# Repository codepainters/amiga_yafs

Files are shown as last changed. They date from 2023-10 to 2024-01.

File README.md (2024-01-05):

# Yet Another FDD Swapper for Amiga 500

This is my project of Amiga FDD swapper, based on `ATtiny 404` MCU. 

## What it does?

It allows for swapping internal `DF0:` drive and `DF1:` external drive (by crossing `SEL0` and `SEL1` signals from `MOS 8520 EVEN CIA`). Holding `Ctrl - Amiga - Amiga` keys for at least 2 seconds switches between normal / swapped configurations. The last used configuration is automatically restored on power up (unless configured not to do so, see below). Switching is confirmed with 1 (for normal) or 2 (for swapped) beeps.

The project consists of 2 separate PCBs:

* a bigger one that goes under the `EVEN CIA` chip - responsible for `SEL0` / `SEL1` swapping.
* a smaller one that which goes between Amiga motherboard and floppy ribbon cable. This PCB allows for internal FDD to be detected as DF1 (it's optional).

This is how the boards look like assembled in my Amiga 500 Rev 6A.

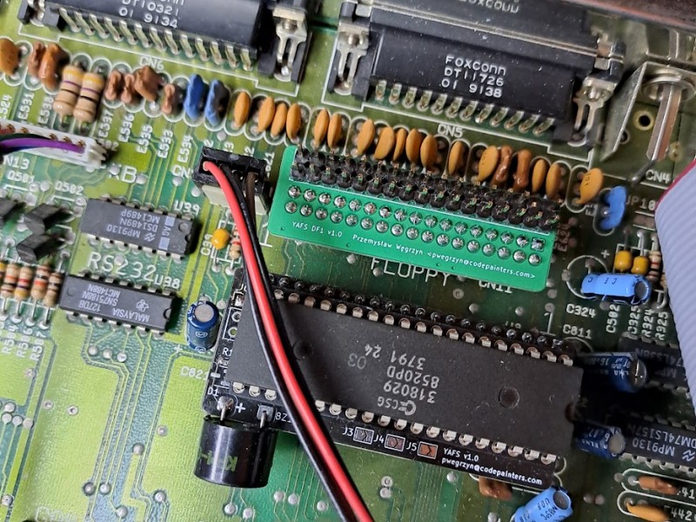
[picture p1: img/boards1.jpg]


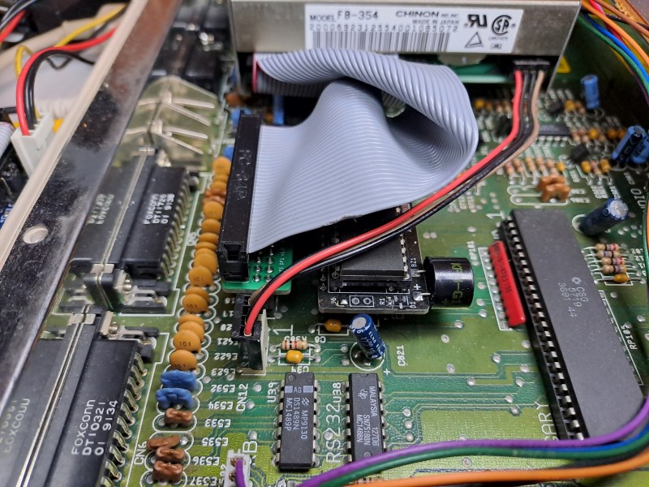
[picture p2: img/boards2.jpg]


## Why another one?

Well, there are many FDD swapper projects already, all of these mods basically swap `SEL0` and `SEL1` of the `Even CIA`, using anything from simple mechanical switch to `74LS153` multiplexer (or even `4066` CMOS analog switch) driven by `ATtiny` MCU. Please note, that swapping `SEL0/1` signals is not enough for internal drive to work as `DF1:`, additional circuitry is needed to drive `~RDY` signal during the drive enumeration at boot time.

Looking for a solution, I've found [Amiga Floppy Swap](https://github.com/retronicdesign/AmigaFloppySwap) project, which is almost exactly what I need. However, I decided to make it slightly simpler:

* my project uses only a single chip, `ATtiny 404` microcontroller, which costs below **0.50 EUR** (at least at the time of this writing),
* the smaller board (which allows for internal drive being enumerated as `DF1:`) doesn't need to be connected with the bigger board. Actually it contains only 2 MOSFETs and 2 resistors and doesn't need any extra connections, beside the floppy flat cable (not even +5V supply!). 
* it is configurable - one can chose if it beeps on every start (or only when changing the configuration) and which configuration (last used vs always swapped vs always straight) it should use upon powering up (see [pcb_cia](pcb_cia) description for details).
* the smaller board is plugged into the mainboard (as opposed to between the cable and FDD) - this way possible collision with the EMI shielding sheet metal is entirely avoided.

Also, it's fun to make something new (even if reinventing the wheel).

## Project files

This repository contains 3 main directories (look there for more details, assembly instructions, etc.):

* [pcb_cia](pcb_cia) - KiCAD project of the bigger PCB which goes under the `CIA` chip.
* [pcb_df1](pcb_df1) - KiCAD project of the smaller PCB which goes between Amiga motherboard and the FDD ribbon cable. 

* [firmware](firmware) for the `ATtiny 404` MCU on the `pcb_cia` board (including programming instructions).

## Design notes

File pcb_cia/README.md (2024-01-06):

# CIA board

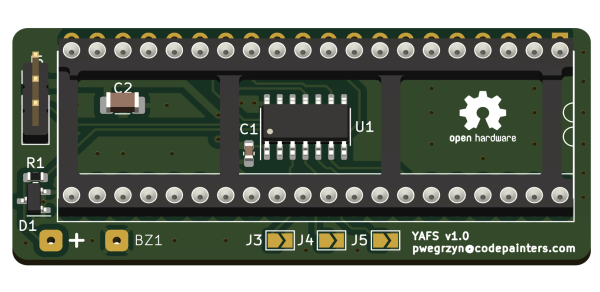
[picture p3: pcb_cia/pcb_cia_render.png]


* [schematics in PDF format](pcb_cia.pdf)
* [Gerbers and Excellon](production/pcb_cia.zip)
* [BOM](production/bom.csv)

Note:

* for `BZ1` buzzer I have used `KPM1201A` magnetic buzzer, but pretty much anything should work, as long as U1 maximum output current (20 mA) is not exceeded. You may need to adjust R1 value.
* I've added `D1` diode as a back EMF protection, but it turned out it is not really necessary with the buzzer I use. 
* for programming instructions, see [here](../firmware)

## Configuration

The J3, J4 and J5 solder bridge jumpers can be used to configure the device:

* if `J3` is open, the buzzer beeps only to confirm the mode changing, if `J3` is closed the buzzer beeps (once or twice) at each power-up, to remind what mode is currently selected.
* if `J4` is open, last used mode is restored on power-up. If it is closed, the same mode is selected at each power-up - swapped (if `J5` is open) or normal (if `J5` is closed). If `J4` is open, `J5` state is ignored.

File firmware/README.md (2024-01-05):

# Firmware

This directory contains the YAFS firmware source code.

**Note:** If you don't want to compile it yourself, you can use precompiled [rel/yafs_1.0.hex](rel/yafs_1.0.hex).

## Compiling

First you need to install `avr-gcc` and `avr-libc`, on Debian/Ubuntu you can simply:

```sh
$ sudo apt-get install avr-gcc avr-libc make
```

And then:

```sh
$ make
```

When `make` completes, `./out/yafs.elf` is ready for programming. 

Notes:

* build is configured for `ATtiny404`, but `ATtiny416` can be selected (initial prototype was developed for `ATtiny416 Xplained Nano` board). You can switch the MCU by changing `MCU_TYPE` value in the `Makefile`. 

* files under `dev` and `include` directories (device specs, headers and runtime libs) come from Microchip. Currently `avr-gcc` is missing definitions for `ATTiny404/416`.

## Programming

The `ATtiny 404` MCU uses `UPDI` single-pin programming / debugging interface. While debugging requires dedicated interface, programming can be done trivially with:

* USB-to-UART dongle (I use cheap Chinese PL2303-based cable).

* single 2k2 or 4k7 resistor

* [avrdude](https://github.com/avrdudes/avrdude) programming tool (one available in Ubuntu should work as well, just `sudo apt-get install avrdude`).

Connect the UART cable and resistor like this (label colors match my UART cable):

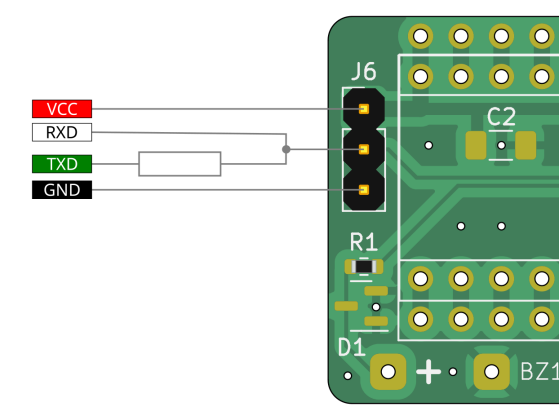
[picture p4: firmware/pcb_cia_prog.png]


Then issue the following command (change `/dev/ttyUSB0` to the actual device corresponding to your USB-to-UART cable):

```sh
avrdude -v -F -b 9600 -c serialupdi -P /dev/ttyUSB0 -p attiny404 -U flash:w:out/yafs.hex:i
```

That's it!

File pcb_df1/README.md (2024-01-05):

# DF1 board

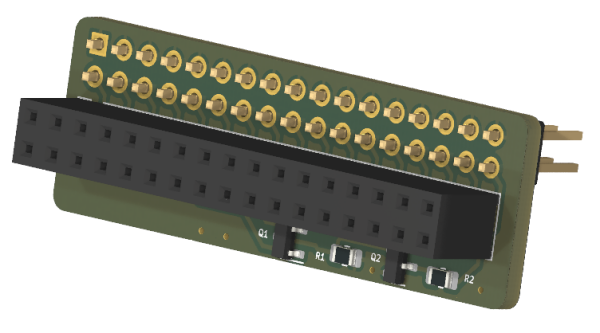
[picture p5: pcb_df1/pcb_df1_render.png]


Note: this is the PCB rendered from the bottom side.

* [schematics in PDF format](pcb_df1.pdf)
* [Gerbers and Excellon](production/pcb_df1.zip)
* [BOM](production/bom.csv)

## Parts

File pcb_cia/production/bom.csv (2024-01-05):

Designator | Footprint | Quantity | Value | LCSC Part #
BZ1 | buzzer | 1 | Buzzer
C1 | 0603 | 1 | 100nF
C2 | 1206 | 1 | 1uF
D1 | SOT-23 | 1 | BAT54C
J1 | DIP-40_W15.24mm | 1 | Pins
J2 | DIP-40_W15.24mm_Socket | 1 | Socket
J3 | SolderJumper-2_P1.3mm_Open_TrianglePad1.0x1.5mm | 1 | CFG1
J4 | SolderJumper-2_P1.3mm_Open_TrianglePad1.0x1.5mm | 1 | CFG2
J5 | SolderJumper-2_P1.3mm_Open_TrianglePad1.0x1.5mm | 1 | CFG3
J6 | PinHeader_1x03_P2.54mm_Vertical | 1 | UPDI
R1 | 0603 | 1 | 120R
U1 | SOIC-14_3.9x8.7mm_P1.27mm | 1 | ATtiny404-SS

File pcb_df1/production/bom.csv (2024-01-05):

Designator | Footprint | Quantity | Value | LCSC Part #
J1 | PinSocket_2x17_P2.54mm_Vertical | 1 | MBoard
J2 | PinHeader_2x17_P2.54mm_Vertical | 1 | Floppy
Q1 | SOT-23 | 1 | DMG2301L
Q2 | SOT-23 | 1 | BSS123
R1 | 0805 | 1 | 2k2
R2 | 0805 | 1 | 100R

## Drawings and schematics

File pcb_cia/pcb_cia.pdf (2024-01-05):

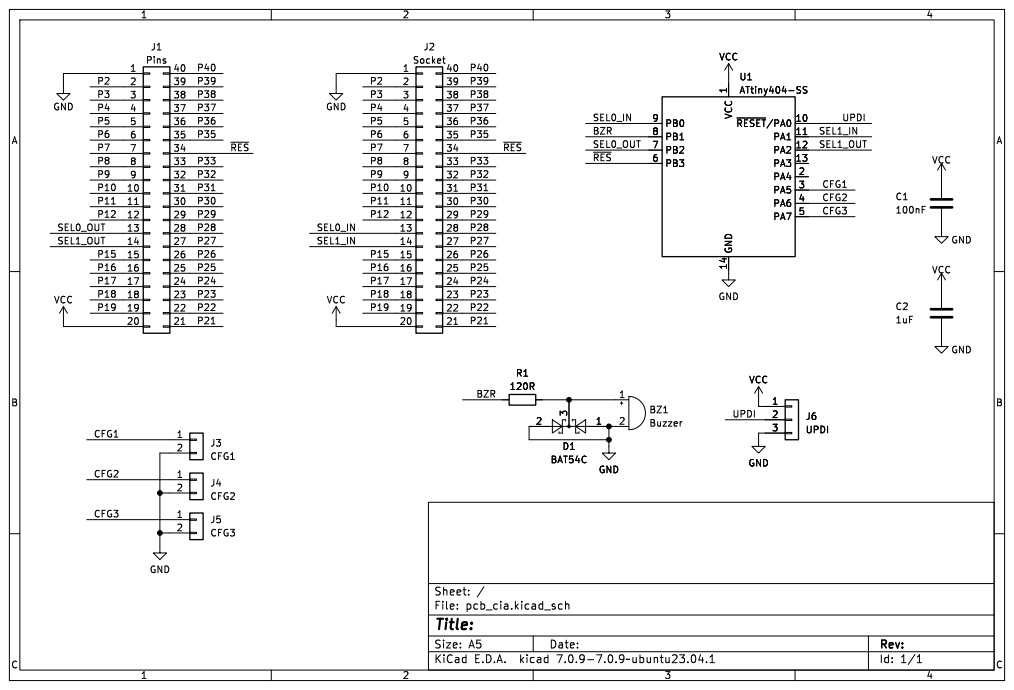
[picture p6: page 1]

1 ~{RESET}/PA010 PA1 11 PA2 12 PA3 13 GND 14 PA4 2 PA5 3 PA6 4 PA7 5 PB3 6 PB2 7 PB1 8 PB0 9 U1ATtiny404-SS GND

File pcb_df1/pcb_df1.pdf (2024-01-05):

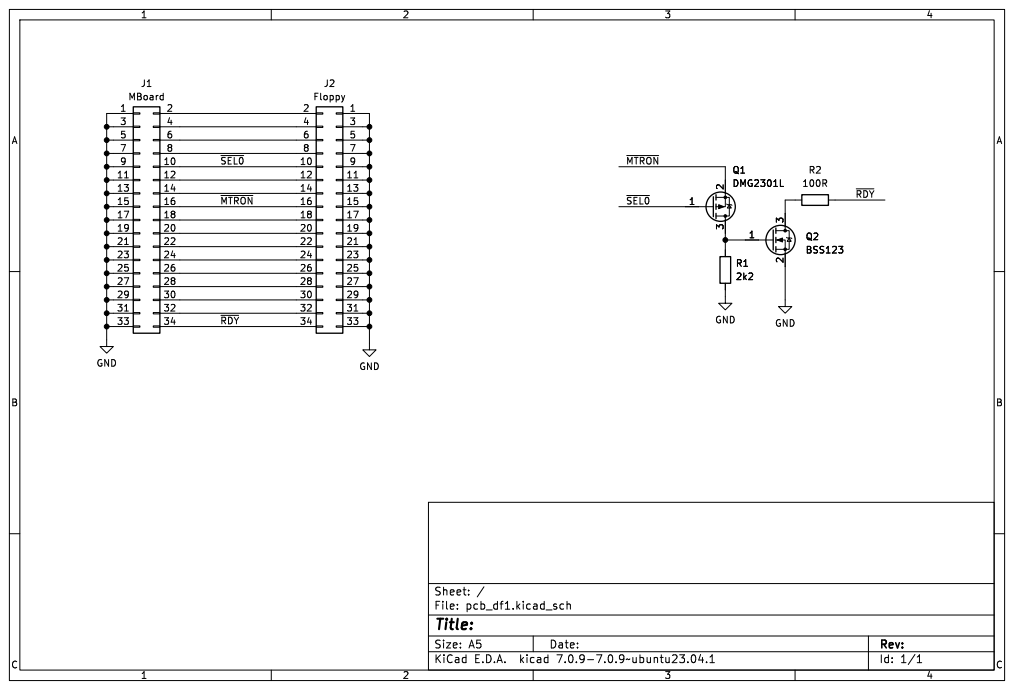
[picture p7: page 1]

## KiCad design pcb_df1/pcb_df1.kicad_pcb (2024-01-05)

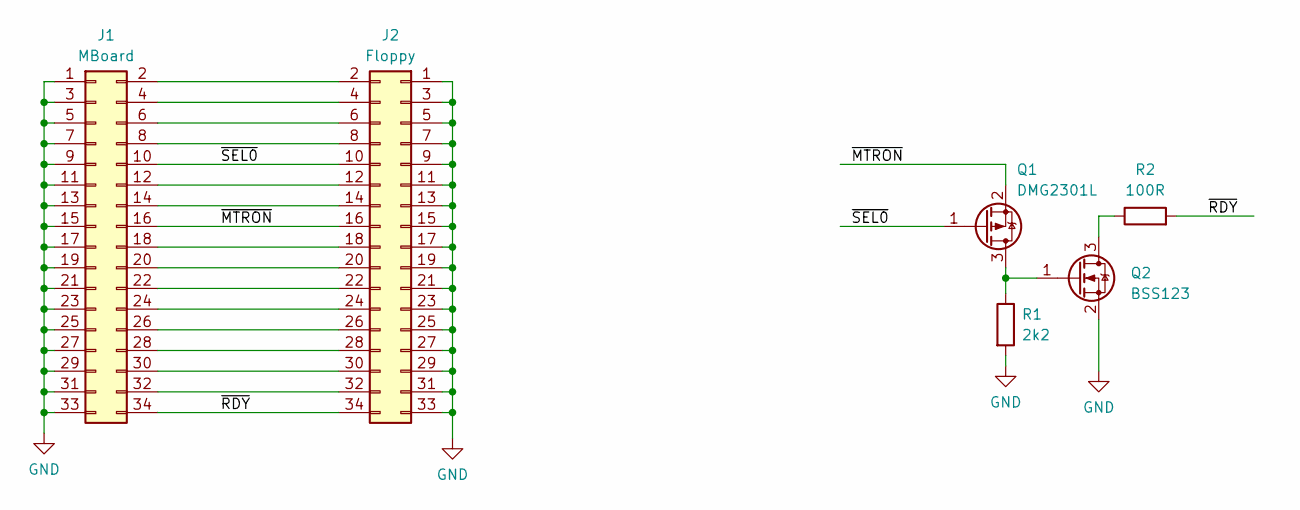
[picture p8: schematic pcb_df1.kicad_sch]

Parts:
J1: MBoard; PinSocket_2x17_P2.54mm_Vertical
J2: Floppy; PinHeader_2x17_P2.54mm_Vertical
Q1: DMG2301L; SOT-23
Q2: BSS123; SOT-23
R1: 2k2; R_0805_2012Metric_Pad1.20x1.40mm_HandSolder
R2: 100R; R_0805_2012Metric_Pad1.20x1.40mm_HandSolder

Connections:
/~MTRON: J1.16, J2.16, Q1.2 (S)
/~RDY: J1.34, J2.34, R2.2
/~SEL0: J1.10, J2.10, Q1.1 (G)
GND: J1.1, J1.3, J1.5, J1.7, J1.9, J1.11, J1.13, J1.15, J1.17, J1.19, J1.21, J1.23, J1.25, J1.27, J1.29, J1.31, J1.33, J2.1, J2.3, J2.5, J2.7, J2.9, J2.11, J2.13, J2.15, J2.17, J2.19, J2.21, J2.23, J2.25, J2.27, J2.29, J2.31, J2.33, Q2.2 (S), R1.2
unnamed: J1.2, J2.2
unnamed: J1.4, J2.4
unnamed: J1.6, J2.6
unnamed: J1.8, J2.8
unnamed: J1.12, J2.12
unnamed: J1.14, J2.14
unnamed: J1.18, J2.18
unnamed: J1.20, J2.20
unnamed: J1.22, J2.22
unnamed: J1.24, J2.24
unnamed: J1.26, J2.26
unnamed: J1.28, J2.28
unnamed: J1.30, J2.30
unnamed: J1.32, J2.32
unnamed: Q1.3 (D), Q2.1 (G), R1.1
unnamed: Q2.3 (D), R2.1

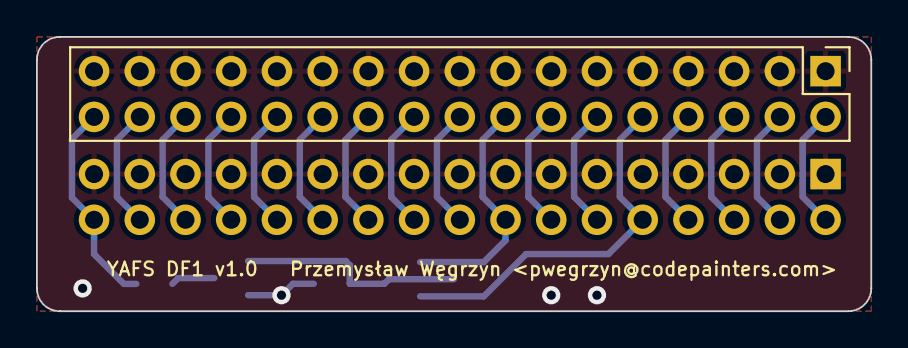
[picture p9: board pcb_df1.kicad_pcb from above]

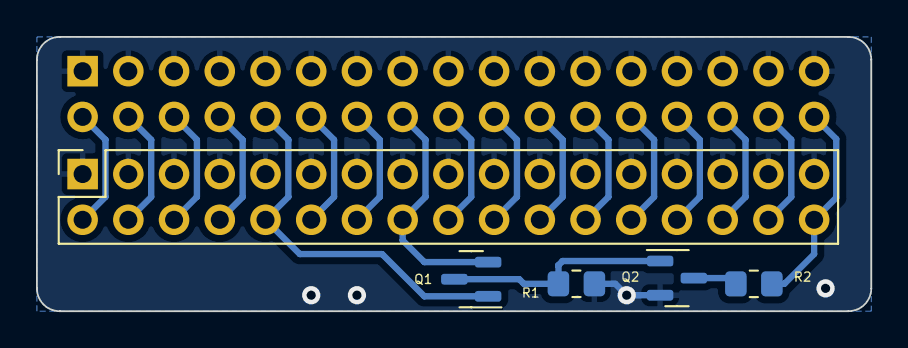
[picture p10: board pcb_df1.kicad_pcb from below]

Board: 2 copper layers, 46.4 x 15.2 mm, 6 parts (5 on the bottom side), 20 nets.

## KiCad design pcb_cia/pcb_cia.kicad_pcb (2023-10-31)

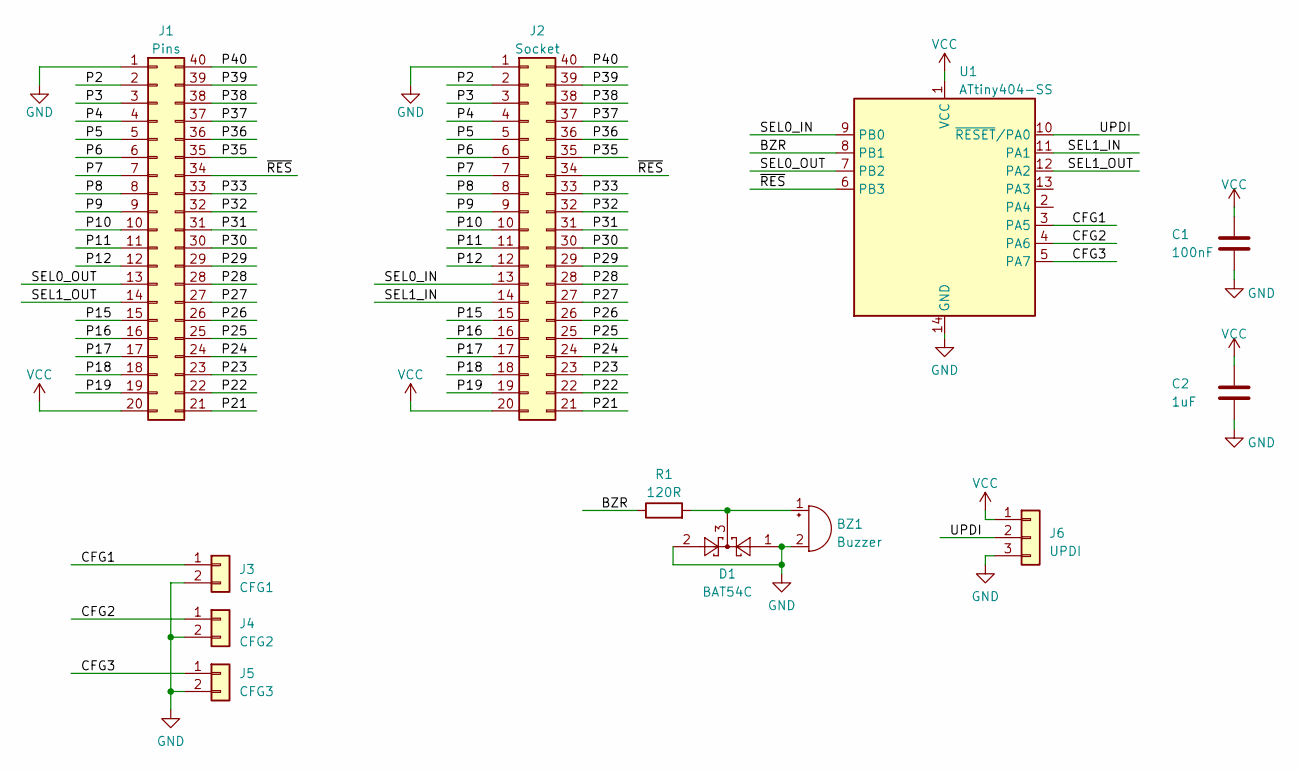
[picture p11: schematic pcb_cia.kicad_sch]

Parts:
BZ1: Buzzer; buzzer
C1: 100nF; C_0603_1608Metric_Pad1.08x0.95mm_HandSolder
C2: 1uF; C_1206_3216Metric_Pad1.33x1.80mm_HandSolder
D1: BAT54C; SOT-23
J1: Pins; DIP-40_W15.24mm
J2: Socket; DIP-40_W15.24mm_Socket
J3: CFG1; SolderJumper-2_P1.3mm_Open_TrianglePad1.0x1.5mm
J4: CFG2; SolderJumper-2_P1.3mm_Open_TrianglePad1.0x1.5mm
J5: CFG3; SolderJumper-2_P1.3mm_Open_TrianglePad1.0x1.5mm
J6: UPDI; PinHeader_1x03_P2.54mm_Vertical
R1: 120R; R_0603_1608Metric
U1: ATtiny404-SS; SOIC-14_3.9x8.7mm_P1.27mm

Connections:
/BZR: R1.1, U1.8 (PB1)
/CFG1: J3.1, U1.3 (PA5)
/CFG2: J4.1, U1.4 (PA6)
/CFG3: J5.1, U1.5 (PA7)
/P2: J1.2, J2.2
/P3: J1.3, J2.3
/P4: J1.4, J2.4
/P5: J1.5, J2.5
/P6: J1.6, J2.6
/P7: J1.7, J2.7
/P8: J1.8, J2.8
/P9: J1.9, J2.9
/P10: J1.10, J2.10
/P11: J1.11, J2.11
/P12: J1.12, J2.12
/P15: J1.15, J2.15
/P16: J1.16, J2.16
/P17: J1.17, J2.17
/P18: J1.18, J2.18
/P19: J1.19, J2.19
/P21: J1.21, J2.21
/P22: J1.22, J2.22
/P23: J1.23, J2.23
/P24: J1.24, J2.24
/P25: J1.25, J2.25
/P26: J1.26, J2.26
/P27: J1.27, J2.27
/P28: J1.28, J2.28
/P29: J1.29, J2.29
/P30: J1.30, J2.30
/P31: J1.31, J2.31
/P32: J1.32, J2.32
/P33: J1.33, J2.33
/P35: J1.35, J2.35
/P36: J1.36, J2.36
/P37: J1.37, J2.37
/P38: J1.38, J2.38
/P39: J1.39, J2.39
/P40: J1.40, J2.40
/SEL0_IN: J2.13, U1.9 (PB0)
/SEL0_OUT: J1.13, U1.7 (PB2)
/SEL1_IN: J2.14, U1.11 (PA1)
/SEL1_OUT: J1.14, U1.12 (PA2)
/UPDI: J6.2, U1.10 (~RESET/PA0)
/~RES: J1.34, J2.34, U1.6 (PB3)
GND: BZ1.2 (+), C1.2, C2.2, D1.1, D1.2, J1.1, J2.1, J3.2, J4.2, J5.2, J6.3, U1.14 (GND)
unnamed: BZ1.1 (-), D1.3, R1.2
VCC: C1.1, C2.1, J1.20, J2.20, J6.1, U1.1 (VCC)

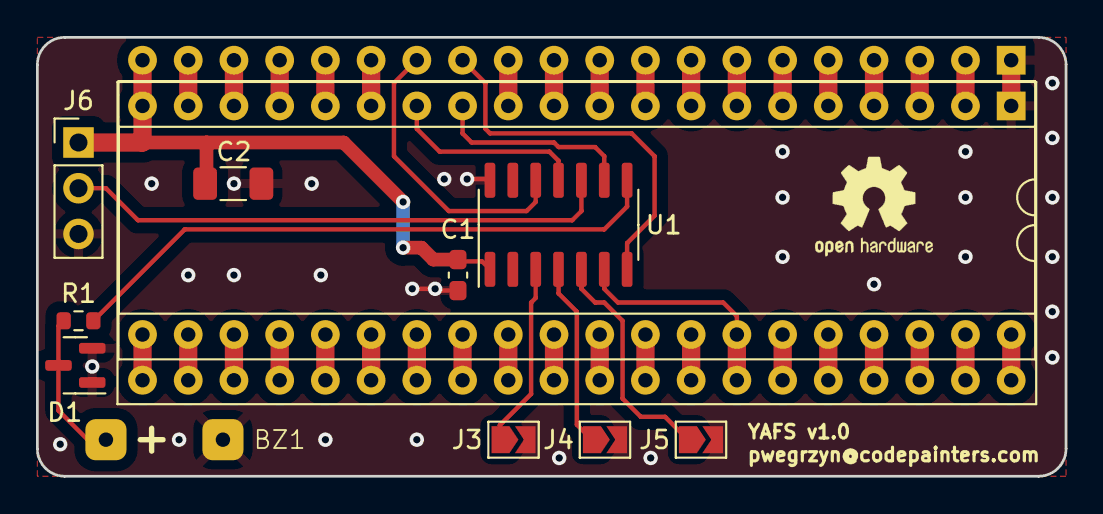
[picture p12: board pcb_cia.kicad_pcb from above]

Board: 2 copper layers, 57.1 x 24.4 mm, 12 parts (0 on the bottom side), 48 nets.

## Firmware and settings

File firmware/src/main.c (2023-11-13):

// SPDX-FileCopyrightText: 2023 Przemysław Węgrzyn <pwegrzyn@codepainters.com>
// SPDX-License-Identifier: MIT

#include <avr/io.h>
#include <avr/interrupt.h>
#include <avr/sleep.h>
#include <stdbool.h>

#include "config.h"
#include "timer.h"

#define ENABLE_PULLUP(port, pin) \
    do { *((uint8_t *) &(port) + 0x10 + pin) |= PORT_PULLUPEN_bm; } while(0)

#define DISABLE_PULLUP(port, pin) \
    do { *((uint8_t *) &(port) + 0x10 + pin) &= ~PORT_PULLUPEN_bm; } while(0)

static bool cfg__beep_on_boot;
static bool cfg__save_last_mode;
static bool cfg__swap_on_start;

static volatile bool switch_pending = false;
static bool drives_swapped;

static volatile int16_t nrst_cnt = NRST_PRESS_DURATION;

#define EEPROM_SWAP_MARKER (0xA5)

static inline void cfg__init() {
    // note: pins are inputs by default, no direction setting necessary, pull-ups are
    // already enabled, too.

    // default (pin open) is no beep, shorted to ground - beep on boot
    cfg__beep_on_boot = (IN_CFG_PORT.IN & (1 << IN_CFG1_PIN)) == 0;
    // default is to save/restore last mode
    cfg__save_last_mode = (IN_CFG_PORT.IN & (1 << IN_CFG2_PIN)) != 0;
    // default is to swap on start (only relevant if cfg__save_last_mode is false)
    cfg__swap_on_start = (IN_CFG_PORT.IN & (1 << IN_CFG3_PIN)) != 0;
}

static void routing__init() {
    OUT_SEL0_PORT.OUTSET = OUT_SEL0_bm;
    OUT_SEL0_PORT.DIRSET = OUT_SEL0_bm;
    OUT_SEL1_PORT.OUTSET = OUT_SEL1_bm;
    OUT_SEL1_PORT.DIRSET = OUT_SEL1_bm;

    OUT_MODE_PORT.DIRSET = OUT_MODE_bm;

    // set PA2/PB2 as EVOUTs
    PORTMUX.CTRLA = 0x03;
    EVSYS.ASYNCCH0 = IN_SEL1_EV;
    EVSYS.ASYNCCH1 = IN_SEL0_EV;
}

static void routing__set(bool swapped) {
    if (swapped) {
        OUT_MODE_PORT.OUT = OUT_MODE_bm;
        // EVOUT0 (PA2) <- ASYNCCH1
        EVSYS.ASYNCUSER8 = EVSYS_ASYNCUSER8_ASYNCCH1_gc;
        // EVOUT1 (PB2) <- ASYNCCH0
        EVSYS.ASYNCUSER9 = EVSYS_ASYNCUSER9_ASYNCCH0_gc;
    } else {
        OUT_MODE_PORT.OUTCLR = OUT_MODE_bm;
        EVSYS.ASYNCUSER8 = EVSYS_ASYNCUSER8_ASYNCCH0_gc;
        EVSYS.ASYNCUSER9 = EVSYS_ASYNCUSER9_ASYNCCH1_gc;
    }
}

uint8_t eeprom__byte_read(uint16_t addr) {
    // hardware stalls execution if EEPROM is busy
    return *(uint8_t *) (EEPROM_START + addr);
}

void eeprom__byte_write(uint16_t addr, uint8_t data) {
    // previous write has to complete
    while (NVMCTRL.STATUS & NVMCTRL_EEBUSY_bm);

    // clear bufer, set byte, erase & write buffer back
    _PROTECTED_WRITE_SPM(NVMCTRL.CTRLA, NVMCTRL_CMD_PAGEBUFCLR_gc);
    *(uint8_t *) (EEPROM_START + addr) = data;
    _PROTECTED_WRITE_SPM(NVMCTRL.CTRLA, NVMCTRL_CMD_PAGEERASEWRITE_gc);
}

static void switch_config() {
    drives_swapped = !drives_swapped;
    if (cfg__save_last_mode) {
        eeprom__byte_write(0, drives_swapped ? EEPROM_SWAP_MARKER : 0);
    }

    routing__set(drives_swapped);
    timer__beep(drives_swapped);
}

int main(void) {
    // enable pull-ups on all pins by default
    for (uint8_t i = 0; i < 8; i++) {
        ENABLE_PULLUP(PORTA, i);
        ENABLE_PULLUP(PORTB, i);
    }

    cfg__init();
    routing__init();

    // these signals are externally pulled up
    DISABLE_PULLUP(IN_NRST_PORT, IN_NRST_PIN);
    DISABLE_PULLUP(IN_SEL0_PORT, IN_SEL0_PIN);
    DISABLE_PULLUP(IN_SEL1_PORT, IN_SEL1_PIN);

    // configure main clock - internal 20MHz / 16 -> 1.25MHz, lock configuration
    _PROTECTED_WRITE(CLKCTRL.MCLKCTRLB, CLKCTRL_PDIV_16X_gc | CLKCTRL_PEN_bm);
    _PROTECTED_WRITE(CLKCTRL.MCLKLOCK, CLKCTRL_LOCKEN_bm);

    timer__init();

    if (cfg__save_last_mode) {
        drives_swapped = eeprom__byte_read(0) == EEPROM_SWAP_MARKER;
    } else {
        drives_swapped = cfg__swap_on_start;
    }
    routing__set(drives_swapped);

    SLPCTRL.CTRLA = SLPCTRL_SEN_bm | SLPCTRL_SMODE_IDLE_gc;
    sei();

    if (cfg__beep_on_boot) {
        timer__delay(600);
        timer__beep(drives_swapped);
    }

#pragma clang diagnostic push
#pragma ide diagnostic ignored "EndlessLoop"
    while (1) {
        sleep_cpu();
        if (switch_pending) {
            switch_config();
            switch_pending = false;
        }
    }
#pragma clang diagnostic pop
}

void timer__tick() {
    bool nrst_active = (IN_NRST_PORT.IN & IN_NRST_bm) == 0;
    if (nrst_active) {
        if (nrst_cnt == 1) {
            switch_pending = true;
            nrst_cnt = 0;
        }
        if (nrst_cnt > 0) {
            nrst_cnt--;
        }
    } else {
        nrst_cnt = NRST_PRESS_DURATION;
    }
}

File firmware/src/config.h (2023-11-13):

// SPDX-FileCopyrightText: 2023 Przemysław Węgrzyn <pwegrzyn@codepainters.com>
// SPDX-License-Identifier: MIT

#ifndef __CONFIG_H__
#define __CONFIG_H__

#include <avr/io.h>

// All configuration pins use PORTA.
#define IN_CFG_PORT    (PORTA)
#define IN_CFG1_PIN    (5)
#define IN_CFG2_PIN    (6)
#define IN_CFG3_PIN    (7)

#define IN_SEL0_PORT   (PORTB)
#define IN_SEL0_PIN    (0)
#define IN_SEL0_EV     (EVSYS_ASYNCCH1_PORTB_PIN0_gc)

#define IN_SEL1_PORT   (PORTA)
#define IN_SEL1_PIN    (1)
#define IN_SEL1_EV     (EVSYS_ASYNCCH0_PORTA_PIN1_gc)

#define OUT_SEL0_PORT   (PORTB)
#define OUT_SEL0_PIN    (2)
#define OUT_SEL0_bm     (1 << OUT_SEL0_PIN)

#define OUT_SEL1_PORT   (PORTA)
#define OUT_SEL1_PIN    (2)
#define OUT_SEL1_bm     (1 << OUT_SEL1_PIN)


#define OUT_BZR_PORT    (PORTB)
#define OUT_BZR_PIN     (1)
#define OUT_BZR_bm      (1 << OUT_BZR_PIN)

#define IN_NRST_PORT    (PORTB)
#define IN_NRST_PIN     (3)
#define IN_NRST_bm      (1 << IN_NRST_PIN)

#define OUT_MODE_PORT   (PORTA)
#define OUT_MODE_PIN    (4)
#define OUT_MODE_bm     (1 << OUT_MODE_PIN)

// 20Mhz / 16 / 625 -> 2kHz
#define TCA0_PERIOD     (625)

// reset press duration required to swap the config,
// expressed in timer ticks, 4000 -> 2s
#define NRST_PRESS_DURATION (4000)

#define BEEP_DURATION (200)

#endif

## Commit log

2023-10-27 DF1 poroject bootstrapped
    [pcb_df1.kicad_pcb, pcb_df1.kicad_sch]
2023-10-31 CIA PCB completed
    [pcb_cia.kicad_pcb, pcb_cia.kicad_sch]
2023-11-02 DF1 (floppy detection) PCB completed.
    [pcb_df1.kicad_pcb, pcb_df1.kicad_sch]
2023-11-02 PCB DF1: slightly bigger vias
    [pcb_df1.kicad_pcb]
2023-11-02 Compined PCB ready for ordering.
    gerberes.zip can be uploaded directly to JLCPCB.
    [combined.kicad_pcb]
2023-11-02 Combined PCB - snap-off tabs widened to 120 mils.
    [combined.kicad_pcb]
2023-11-02 pcb_df1: changed orinetation
    [pcb_df1.kicad_pcb]
2023-11-02 Combined PCB: redone to fix silk screen labels orientation
    [combined.kicad_pcb]
2023-11-02 Combined PCB - larger slot, as per JLCPCB request.
    [combined.kicad_pcb]
2023-11-27 DF1 board reworked
    New version sits on the other end of the flat cable.
    [pcb_df1.kicad_pcb, pcb_df1.kicad_sch]
2023-11-28 Dropping combined board, JLC doesn't like it ;)
    [combined.kicad_pcb]
2023-11-28 DF1: GND fills reworked
    [pcb_df1.kicad_pcb]
2023-12-03 Added production output for DF1 board (gerbers, BOM, etc.)
    [bom.csv, designators.csv, positions.csv]
2024-01-05 DF1: R1 value fixed
    [pcb_df1.kicad_pcb, pcb_df1.kicad_sch]
2024-01-05 pcb_df1: updated production files
    [bom.csv, designators.csv, positions.csv]
2024-01-05 pcb_df1: added schematic PDF
2024-01-05 pcb_cia: gerbers
    [bom.csv]
2024-01-05 pcb_df1: README file
2024-01-05 pcb_cia schematics as PDF
2024-01-06 Updated README for CIA PCB (configuration).
